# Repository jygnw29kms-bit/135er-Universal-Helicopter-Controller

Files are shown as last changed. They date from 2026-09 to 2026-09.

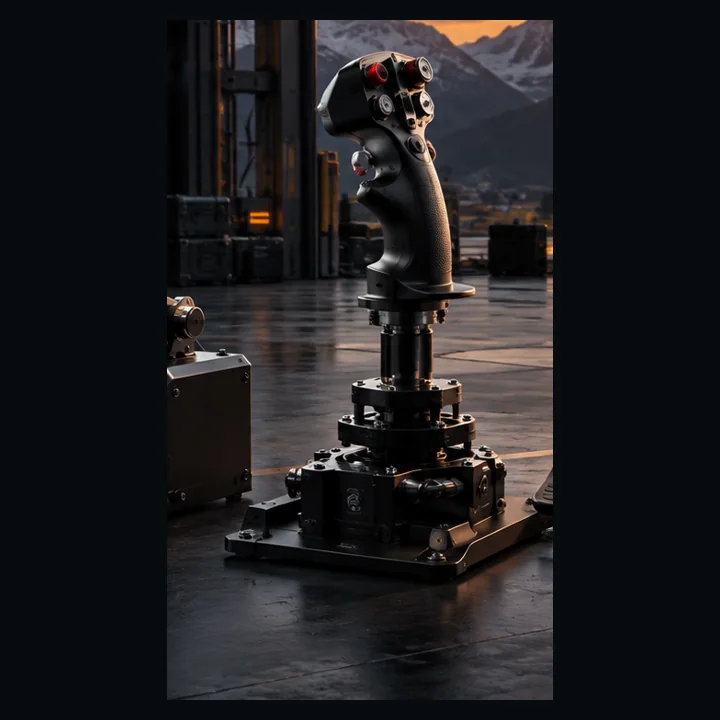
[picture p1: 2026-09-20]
site/assets/cyclic-render.webp

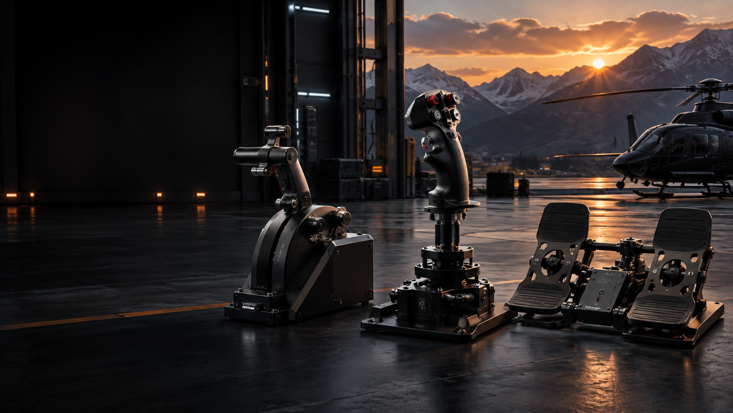
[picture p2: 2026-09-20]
site/assets/hero-render.png

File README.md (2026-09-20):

# 135er Universal Helicopter Controller

Open-source, cross-platform helicopter flight controls for Microsoft Flight Simulator, X-Plane and other simulators.

## Current branch: V1.1 engineering / RC2 candidate

The original V1 RC1 proved the basic architecture and automated build flow. V1.1 hardens the design before physical validation.

Current scope:

- Cyclic: pitch + roll
- Collective: collective + twist throttle
- Pedals: anti-torque yaw + independent left/right toe brakes
- Seven contactless Hall-based analog axes
- Raspberry Pi Pico 2 / RP2350 main controller
- MCP3208 external SPI ADC
- Standard USB HID joystick
- USB CDC diagnostic/configuration console
- 32 HID button bits + 8-way hat
- eight direct debounced button inputs in the first wiring revision
- persistent calibration in flash
- FDM-first PETG mechanical design
- automated STL, host-test and firmware builds

> No V1.x build is physically validated yet. CI success proves that the firmware compiles and CAD renders; it does not prove fit, strength, ergonomics or flight quality.

## Architecture

```text
7 x AS5600 magnetic angle sensors (analog OUT)
                 |
                 v
        MCP3208 8-channel SPI ADC
                 |
                 v
        Raspberry Pi Pico 2 / RP2350
           |                 |
           v                 v
       USB HID          USB CDC console
           |
   Windows / Linux / macOS
           |
      MSFS / X-Plane
```

Using analog output avoids the fixed-I2C-address problem that appears when several AS5600 modules share one bus.

## Axes

1. Cyclic Roll
2. Cyclic Pitch
3. Collective
4. Twist Throttle
5. Anti-Torque Pedals
6. Left Toe Brake
7. Right Toe Brake

## Firmware V1.1 improvements

- real persistent calibration with CRC validation
- first-sample filter seeding; no artificial startup sweep
- configurable filter, inversion, center deadzone and bipolar expo
- direct button and hat input support
- unique USB serial number per Pico 2
- CDC console for calibration and diagnostics
- 1 ms scheduler with overrun counter
- MCP3208 acquisition budget corrected from the original RC1 implementation
- host regression tests for axis math

See `docs/FIRMWARE_V1_1.md`.

## Mechanical V1.1 improvements

- real toe-brake printable modules
- dedicated collective friction adjuster
- modular split cyclic grip with switch openings
- dedicated electronics tray and ventilated lid
- steel primary shafts and bearings remain mandatory
- replaceable Hall sensor carriers and magnet interfaces

## Repository

```text
cad/
  cyclic/
  collective/
  pedals/
  electronics/
  validation/
firmware/
hardware/
docs/
profiles/
site/
.github/workflows/
```

## FDM rules

- target printer envelope: 256 x 256 x 256 mm
- PETG baseline; ASA optional after fit validation
- support-free geometry wherever practical
- steel shafts for primary pivots
- bearings for precision rotation
- M3/M4/M5/M6 standard hardware
- fit-critical dimensions are frozen only after coupon testing

## Print-first workflow

1. Print the validation plate / fit coupons.
2. Record best bearing, shaft, tube, magnet and fastener fits.
3. Freeze dimensional compensation for the actual printer/filament.
4. Print and assemble Cyclic first.
5. Validate Hall alignment and controls.
6. Continue with Collective.
7. Continue with Pedals and toe brakes.
8. Install electronics enclosure and harness.
9. Calibrate through the CDC console.
10. Test MSFS and X-Plane.
11. Only after the validation checklist passes may a release be labeled **VALIDATED**.

## Research basis

The project has been compared against FreeJoy, OpenFFBoard, several open helicopter-collective projects and 3D-printable Hall joystick projects. Adopted ideas and license boundaries are documented in `docs/RESEARCH_NOTES.md`.

No GPL source code from FreeJoy is copied into this MIT firmware.

## Documentation

- `docs/ASSEMBLY_V1.md`
- `docs/FIRMWARE_V1_1.md`
- `docs/PRINTING.md`
- `docs/CALIBRATION.md`
- `docs/VALIDATION_CHECKLIST.md`
- `docs/RC1_STATUS.md`
- `docs/RESEARCH_NOTES.md`
- `hardware/BOM_V1_RC1.md`

## License

Software: MIT.

Hardware/CAD source remains open and the final dedicated hardware-license file will be frozen before the first physically validated release.

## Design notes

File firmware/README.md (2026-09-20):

# Firmware V1.1

Target: Raspberry Pi Pico 2 / RP2350 using Pico SDK and TinyUSB.

## Inputs

Analog chain:

```text
7 x AS5600-class Hall angle sensors (analog OUT)
-> MCP3208
-> RP2350
```

Axis order:
1. Cyclic Roll
2. Cyclic Pitch
3. Collective
4. Twist Throttle
5. Pedals
6. Left Toe Brake
7. Right Toe Brake

Digital V1.1:
- GPIO2..9: buttons 1..8, active low
- GPIO10..13: four-way hat, active low
- five-sample debounce

The HID report still reserves 32 button bits for future expansion.

## USB

Composite USB device:
- HID joystick
- CDC serial configuration/diagnostics

The HID interface exposes seven 16-bit logical axes, 32 buttons and one 8-way hat.

## Calibration

Calibration is stored in the last flash sector with a version field and CRC.

Use the CDC console:

```text
help
status
cal show
cal set roll 800 8100 15400
deadzone roll 120
filter roll 2
expo roll 10
invert roll 0
save
```

See `docs/FIRMWARE_V1_1.md` and `docs/CALIBRATION.md`.

## Timing

MCP3208 SPI runs at 1 MHz. Four readings are accumulated per axis per frame. The main report schedule targets 1 ms and counts overruns for validation.

The four-sample accumulation uses a 0..16380 numeric calibration domain; it must not be described as guaranteed 14-bit ADC ENOB.

## Build

```bash
export PICO_SDK_PATH=/path/to/pico-sdk
cmake -S firmware -B build -DPICO_BOARD=pico2
cmake --build build -j
```

CI also compiles and runs host-side regression tests for axis processing.

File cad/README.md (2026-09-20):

# CAD

All mechanical modules are designed FDM-first.

## Directories

- cyclic/
- collective/
- pedals/
- grips/

## Design requirements

- Every printable part must fit a 256 x 256 mm bed
- Prefer support-free geometry
- Avoid long unsupported bridges
- Prefer screw-fastened assemblies over glued shells
- Use replaceable sensor carriers
- Use metal shafts and bearings for critical pivots
- PETG is the baseline material

Native CAD source files and export STL/3MF files will be added after validation.

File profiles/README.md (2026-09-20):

# Profiles

Profiles will map one physical controller to different helicopter control philosophies.

Initial profile families:

- Universal Helicopter
- Robinson
- Bell
- Airbus / FADEC
- Military
- Custom

Profiles may define:

- Axis curves
- Dead zones
- Collective response
- Twist-throttle behavior
- Governor behavior
- Trim mode
- Button assignments
- Simulator-specific notes

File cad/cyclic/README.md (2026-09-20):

# Cyclic CAD

## First prototype scope

The first CAD iteration will contain:

- Base frame
- Roll gimbal
- Pitch gimbal
- Stick clamp
- Two Hall sensor mounts
- Optional spring mounts
- Top service cover
- Grip interface

## Export policy

For each validated revision, include:

- Native CAD source
- STEP
- STL
- Optional 3MF print project

## Print orientation

Every part should have an obvious flat orientation. Parts that require support should be redesigned unless there is a strong structural reason not to.

## Prototype naming

Use revision naming like:

```text
cyclic_base_v0.1
cyclic_roll_gimbal_v0.1
cyclic_pitch_gimbal_v0.1
cyclic_sensor_mount_v0.1
```

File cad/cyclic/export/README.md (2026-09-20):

# Cyclic exports

This folder will contain validated STL/STEP/3MF exports.

Current source geometry lives in `../src/`.

Do not treat an export as production-ready until it has:
1. printed successfully,
2. passed fit checks for bearings/shafts,
3. passed Hall sensor alignment checks,
4. received a tagged revision.

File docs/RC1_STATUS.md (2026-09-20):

# V1.1 / RC2 engineering status

The project has moved beyond the original RC1 implementation. RC1 remains a useful historical milestone, but the main branch now contains the V1.1 engineering hardening work intended to become RC2.

## Implemented

- RP2350 / Pico 2 target
- seven Hall-based analog axes
- MCP3208 SPI acquisition
- standard USB HID joystick
- composite USB CDC diagnostics/configuration
- 32 HID button bits plus 8-way hat
- eight direct debounced button inputs
- persistent CRC-protected calibration in flash
- configurable inversion, filtering, deadzone and bipolar expo
- unique USB serial number
- acquisition overrun diagnostics
- host-side axis regression tests
- cyclic, collective and pedal CAD
- actual toe-brake CAD modules
- collective friction adjuster
- split cyclic grip prototype
- Pico/MCP3208 electronics enclosure
- automated CAD and firmware builds

## Not physically validated

No V1.x release is allowed to be called VALIDATED until a real printed controller has passed:
- fit coupons
- bearing/shaft/tube fit
- mechanical travel and hard-stop tests
- Hall alignment
- measured calibration
- USB enumeration
- button/hat tests
- sustained overrun check
- MSFS/X-Plane mapping
- extended flight test

## Remaining before RC2 freeze

- print validation plate
- freeze P2S/PETG dimensional compensation
- confirm toe-brake pivot geometry on a physical pedal
- confirm cyclic grip ergonomics and switch selection
- confirm collective friction material and preload
- create final wiring harness drawing
- evaluate dedicated PCB after breadboard/prototype validation

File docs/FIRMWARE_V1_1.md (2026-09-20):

# Firmware V1.1 engineering notes

## Signal path

```
7x AS5600 analog OUT
      |
      v
MCP3208 (SPI, 1 MHz)
      |
      v
4 samples/channel per frame
      |
      v
per-axis IIR filter
      |
      v
calibration + deadzone + optional expo
      |
      v
16-bit logical HID axis
```

The MCP3208 remains a 12-bit ADC. Four samples are accumulated into the existing 0..16380 calibration domain. Do not describe this as a guaranteed 14-bit ENOB measurement.

## 1 ms scheduling

The earlier 16-sample/channel implementation could not meet a true 1 ms seven-axis cycle at the configured SPI speed. V1.1 uses four samples per channel at 1 MHz and tracks missed scheduling windows with `loop_overruns`.

## USB

The controller enumerates as a composite device:
- standard joystick HID
- CDC serial configuration console

HID exposes:
- 7 axes
- 32 button bits
- one 8-way hat

V1.1 directly wires eight debounced buttons. The remaining HID button bits are reserved for future matrix/shift-register expansion.

## Default direct GPIO map

- GPIO2..GPIO9: Buttons 1..8, active low
- GPIO10: Hat Up
- GPIO11: Hat Right
- GPIO12: Hat Down
- GPIO13: Hat Left
- GPIO16: MCP3208 MISO
- GPIO17: MCP3208 CS
- GPIO18: MCP3208 SCK
- GPIO19: MCP3208 MOSI

Inputs use the Pico internal pull-ups.

## Calibration console

Connect to the CDC serial port. Commands:

```text
help
status
cal show
cal set <axis> <min> <center> <max>
invert <axis> <0|1>
deadzone <axis> <0..32766>
filter <axis> <0..5>
expo <axis> <0..100>
save
defaults
```

Axis names:
`roll pitch collective throttle pedals brake_left brake_right`

Changes are made in RAM first. Use `save` to write a CRC-protected configuration to the final flash sector.

## Physical validation rule

Before saving final calibration:
1. verify magnet alignment,
2. move each mechanism through full mechanical travel,
3. inspect `status` raw values,
4. leave electrical headroom before mechanical hard stops,
5. enter measured min/center/max,
6. test simulator direction and center,
7. only then save.

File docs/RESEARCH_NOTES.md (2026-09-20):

# Design research and adopted patterns

This document records concepts reviewed from other open-source simulator-control projects and what was deliberately adopted or rejected.

## Reviewed projects

### FreeJoy
Useful concepts:
- per-axis calibration
- configurable filtering
- inversion/deadzone/curve processing
- buttons, hats and encoders as independent input sources
- MCP3208 support as an external ADC

License note: FreeJoy is GPL-3.0. No FreeJoy source code is copied into this MIT-licensed firmware. Only general architectural ideas are used.

### OpenFFBoard
Useful concepts:
- modular input-source architecture
- separation of input acquisition from USB report generation
- runtime configuration/diagnostics
- CAN as a sensible future expansion path

Not adopted for V1:
- force-feedback motor stack
- HID PID/FFB implementation

### JRNitre/JoystickFreeJoy
Useful concepts:
- 3D-printable modular gimbal construction
- precision bearings and steel hardware instead of printed primary shafts
- contactless high-resolution magnetic sensing
- replaceable sensor/magnet geometry

### KalebClark/HeliCollective
Useful concepts:
- dedicated collective friction hardware
- separate handle/hat components
- serviceable modular parts rather than one monolithic print

### JoePrimo/Helicopter-Collective
Useful concepts:
- button matrix / encoder handling
- practical simulator-oriented grip controls

### geoff-coppertop/helicopter-collective
Useful concepts:
- RP2350 as target MCU
- separation of hardware-independent processing logic from peripheral code
- host-side tests for filtering and processing logic
- diagnostics/status interface

## Adopted for 135er V1.1

- central hardware configuration file
- first-sample filter seeding to remove startup transients
- configurable per-axis filter strength
- center deadzone with range re-scaling
- optional bipolar expo
- persistent calibration in Pico 2 flash
- CDC serial configuration/diagnostic console
- direct debounced buttons plus 8-way hat
- unique USB serial number derived from the Pico board ID
- acquisition timing corrected for the real MCP3208 transaction budget
- loop-overrun counter
- host regression tests for axis processing
- toe-brake mechanical modules
- collective friction adjuster
- split cyclic grip with switch openings
- dedicated electronics tray and lid

## Deliberately deferred

- FFB / active cyclic
- force trim motors/clutches
- CAN/RS485 remote modules
- 32-button shift-register expansion
- graphical desktop configurator
- dedicated controller PCB
- automatic calibration wizard

These belong to later revisions after the passive V1 hardware has been physically validated.

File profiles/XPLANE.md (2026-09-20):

# X-Plane profile

Suggested logical mapping:
- Cyclic Roll -> Roll
- Cyclic Pitch -> Pitch
- Collective -> Collective
- Throttle -> throttle assignment required by the helicopter model
- Pedals -> Yaw
- Toe brakes -> left/right toe brake

Start with linear output and save aircraft-specific response curves in simulator profiles.

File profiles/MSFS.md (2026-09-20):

# Microsoft Flight Simulator profile

Suggested logical mapping:
- Cyclic Roll -> helicopter cyclic lateral / roll axis
- Cyclic Pitch -> helicopter cyclic longitudinal / pitch axis
- Collective -> helicopter collective axis
- Throttle -> helicopter throttle / engine control as required by aircraft
- Pedals -> rudder / anti-torque axis
- Toe brakes -> left/right brake axes

Keep firmware curves linear initially. Apply aircraft-specific sensitivity only after physical calibration.

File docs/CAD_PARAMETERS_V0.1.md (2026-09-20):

# CAD Parameters V0.1

These values are the mechanical baseline for the first Cyclic V1 prototype.

## Global FDM constraints

- Build volume target: 256 x 256 x 256 mm minimum
- Primary material: PETG
- Nominal nozzle: 0.4 mm
- Nominal layer height: 0.20 mm
- Standard wall: 3.2 mm
- Reinforced wall: 5.0-6.0 mm
- Moving-part clearance: 0.30 mm nominal
- Loose service clearance: 0.40 mm nominal
- Bearing pocket allowance: start at +0.10 mm diameter and tune by printer
- Avoid support where possible
- Maximum intended unsupported overhang: 45 deg

## Cyclic base

- Base envelope target: 220 x 180 x 75 mm
- Mounting hole pattern: TBD after first gimbal frame
- Service cover removable from top
- Sensor carriers removable independently from structural gimbal

## Cyclic stick

- Pivot-to-grip reference length: 480 mm
- Tube OD target: 20-22 mm
- Preferred tube: aluminium
- Clamp style: split clamp with M4 fasteners

## Gimbal

- Pitch travel: +/-15 deg
- Roll travel: +/-15 deg
- Main pivot shaft: 8 mm steel
- Bearings: 608-2RS, 8 x 22 x 7 mm
- Gimbal arms should print flat whenever practical
- Bearing housings should be split or clamp-style rather than blind press fits

## Hall sensor geometry

Initial target sensor family:
- AS5600-class absolute magnetic angle sensor for prototype
- Diametric magnet mounted concentric with shaft
- Adjustable sensor gap target: 1-3 mm
- Sensor mount to include slotted adjustment in at least one axis

## Centering

- V1 supports no-spring/free mode
- Optional light centering springs
- Spring anchors must be adjustable
- No mandatory hard center detent

## Fasteners

Preferred standardization:
- M3 for electronics and sensor carriers
- M4 for printed structural joints
- M8 only where used as an actual pivot/shaft substitute

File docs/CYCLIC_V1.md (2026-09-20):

# Cyclic V1

## Baseline geometry

- Floor-mounted dual-gimbal cyclic
- Stick length from pivot: approx. 480 mm
- Pitch travel: approx. +/-15 deg
- Roll travel: approx. +/-15 deg
- Stick tube: 20-22 mm aluminium tube
- Main shafts: 8 mm steel
- Bearings: 608-2RS
- Base target: approx. 220 x 180 x 75 mm

## Sensor concept

Each axis uses a contactless magnetic angle sensor.

- Magnet mounted concentrically on the axis
- Replaceable printed sensor carrier
- No gears or linkages between shaft and sensor
- Target sensor gap: 1-3 mm depending on final sensor choice

## FDM rules

- PETG baseline
- Standard wall thickness: 3.2 mm
- Structural zones: 5-6 mm
- Moving PETG interfaces: 0.25-0.35 mm clearance
- Design for support-free orientation wherever possible
- Split large components into mechanically keyed screw-fastened parts

## V1 printed parts

- Base bottom
- Base left
- Base right
- Pitch gimbal
- Roll gimbal
- Stick clamp A
- Stick clamp B
- X sensor mount
- Y sensor mount
- Spring mounts
- Cover
- Grip halves

## Controls in the grip

- 4-way trim hat
- PTT
- Force-trim release
- Two spare buttons

## Centering

Three intended modes:

- Free: no centering springs
- Light: very soft centering
- Normal: stronger centering for joystick-like preference

Final spring geometry will be adjustable via slotted mounts.

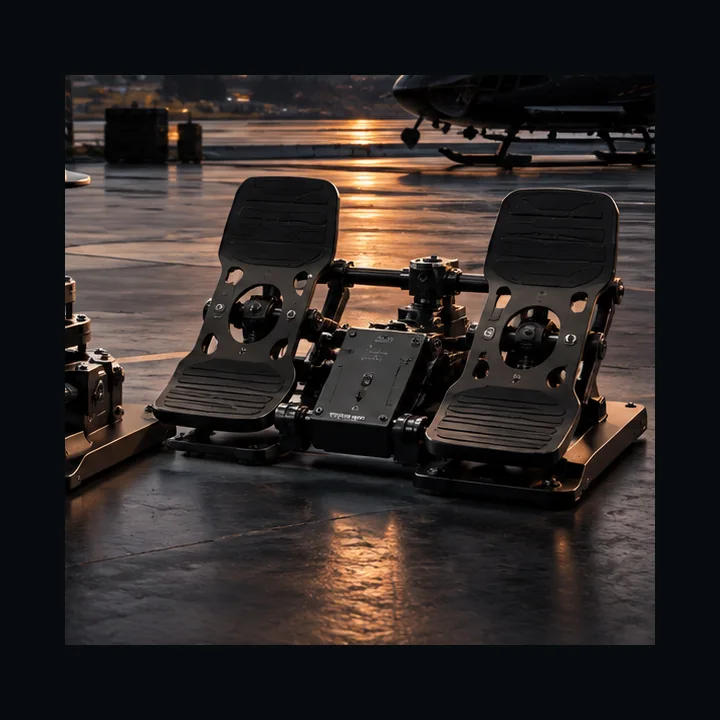
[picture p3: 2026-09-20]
site/assets/pedals-render.webp

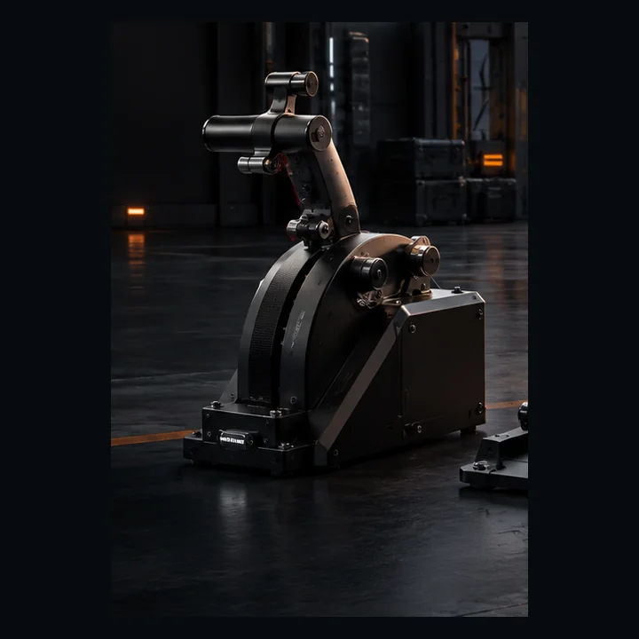
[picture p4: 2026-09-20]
site/assets/collective-render.webp

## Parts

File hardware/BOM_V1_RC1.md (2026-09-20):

# BOM V1.1 / RC2 candidate

## Electronics
- 1x Raspberry Pi Pico 2 (RP2350)
- 1x MCP3208 8-channel 12-bit SPI ADC
- 7x AS5600 magnetic angle sensor modules with analog OUT available
- 7x compatible diametrically magnetized magnets, nominal 6 mm diameter
- 1x USB data cable
- 8x momentary switches minimum for the first direct-button build
- 1x four-way hat mechanism or four momentary switches
- JST-XH or equivalent locking connectors for serviceable module wiring
- 3.3 V sensor rail and common ground distribution

### Recommended signal-integrity parts
For custom/bare sensor carriers rather than finished modules:
- local ceramic decoupling close to each sensor
- MCP3208 supply/reference decoupling close to the ADC
- small bulk capacitor on the sensor rail
- keep analog sensor runs away from USB and fast digital wiring where practical
- join analog/digital grounds cleanly and avoid high-current return paths through sensor ground

Verify what capacitors are already populated on purchased AS5600 breakout boards before duplicating them.

## Cyclic
- 4x 608-2RS bearings minimum
- 2x 8 mm steel shafts
- 1x 20-22 mm OD aluminium tube, about 500 mm
- M3 hardware for sensor/switch modules
- M4 structural screws, washers and lock nuts
- optional light extension springs
- switches for PTT / force-trim / spare functions

## Collective
- bearings to suit final 10 mm pivot arrangement
- 1x 10 mm steel shaft
- 1x 20-22 mm OD aluminium tube
- M4/M5 fasteners
- friction washers/material plus M5 friction-adjuster hardware
- optional rotary encoder / additional switches for aircraft-specific controls

## Pedals
- bearings to suit final 10 mm center pivot
- 1x 10 mm steel center shaft
- 2x 6 mm toe-brake pivot shafts
- M5/M6 structural fasteners
- return springs for left/right toe brake
- three Hall sensor mounts total: yaw + two toe-brake axes

## Printing
- PETG baseline for V1
- ASA optional after dimensional validation
- 0.4 mm nozzle
- 0.20 mm layer height
- 4 perimeters on structural parts
- 30-40% infill baseline
- local reinforcement around pivots/lever/rocker as required

No printed part is intended to replace the primary steel pivot shafts.

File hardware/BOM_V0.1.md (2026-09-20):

# Preliminary BOM V0.1

This is the architecture-stage BOM and will be refined after the first CAD iteration.

## Controller

- 1x RP2350 development board / controller board
- 1x USB-C connection
- Wiring/connectors
- Optional CAN or RS485 transceivers for modular expansion

## Cyclic

- 2x contactless magnetic angle sensors
- 2x compatible diametric magnets
- 4x 608-2RS bearings minimum, final quantity TBD
- 8 mm steel shaft material
- 20-22 mm aluminium tube for cyclic stick
- M3 fasteners for sensors/electronics
- M4 fasteners for structural printed parts
- Optional light extension springs

## Collective

- 2x Hall / magnetic angle sensors
- Bearings and steel pivot shaft
- Aluminium tube
- Buttons/switches for governor, starter and auxiliary functions

## Pedals

- 1x yaw Hall / magnetic sensor
- Optional 2x toe-brake Hall sensors
- Steel main shaft
- Bearings
- M4 structural hardware

## Printing

Baseline material: PETG.
Higher-load alternatives may include ASA or reinforced engineering filament where appropriate.

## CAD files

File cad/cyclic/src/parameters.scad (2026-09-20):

// 135er Universal Helicopter Controller - Cyclic V1 parameters
$fn = 64;

base_x = 220;
base_y = 180;
base_h = 18;
wall = 5;

shaft_d = 8.2;
bearing_od = 22.2;
bearing_w = 7.2;

gimbal_outer_x = 120;
gimbal_outer_y = 100;
gimbal_bar = 18;
gimbal_h = 18;

tube_od = 22.2;
tube_clamp_wall = 6;

sensor_board_x = 23;
sensor_board_y = 23;
sensor_gap = 2.0;

m4_clearance = 4.4;
m3_clearance = 3.4;

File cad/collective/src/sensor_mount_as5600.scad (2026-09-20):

include <../../common.scad>
px=42;py=42;ph=4;m3=3.4;m4=4.5;
difference(){plate(px,py,ph,3);cylinder(h=20,d=12,center=true);for(x=[-9,9])for(y=[-9,9])translate([x,y,-1])cylinder(h=ph+2,d=m3);for(x=[-15,15])translate([x,0,0])slot3d(12,m4,ph+2);}

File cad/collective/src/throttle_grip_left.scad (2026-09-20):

$fn=64;len=145;od=42;id=22.7;
difference(){intersection(){rotate([0,90,0])cylinder(h=len,d=od,center=true);translate([0,12,0])cube([len+4,od,od+4],center=true);}rotate([0,90,0])cylinder(h=len+4,d=id,center=true);}

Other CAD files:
cad/collective/src/throttle_grip_right.scad
cad/collective/src/base.scad
cad/collective/src/friction_adjuster.scad
cad/collective/src/lever_root.scad
cad/common.scad
cad/cyclic/src/base.scad
cad/cyclic/src/gimbal_pitch.scad
cad/cyclic/src/gimbal_roll.scad
cad/cyclic/src/grip_front.scad
cad/cyclic/src/grip_rear.scad
cad/cyclic/src/magnet_hub.scad
cad/cyclic/src/preview_assembly.scad
cad/cyclic/src/sensor_mount_as5600.scad
cad/cyclic/src/stick_clamp.scad
cad/electronics/src/controller_lid.scad
cad/electronics/src/controller_tray.scad
cad/pedals/src/base.scad
cad/pedals/src/pedal_left.scad
cad/pedals/src/pedal_right.scad
cad/pedals/src/rocker.scad
cad/pedals/src/sensor_mount_as5600.scad
cad/pedals/src/toe_brake_left.scad
cad/pedals/src/toe_brake_right.scad
cad/validation/src/fit_coupons.scad
cad/validation/src/validation_plate_01.scad

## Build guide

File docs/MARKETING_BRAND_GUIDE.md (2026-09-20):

# 135er Heli Control — Brand & Marketing Guide

## Positioning

135er Heli Control is an open helicopter-control platform for serious simulator pilots.

It is not positioned as:
- a generic joystick
- a loose STL collection
- a GitHub experiment

It is positioned as:
- a complete helicopter-control system
- built around real helicopter control logic
- modular and serviceable
- contactless on all primary analog axes
- open by design

## Primary brand name

**135er Heli Control**

Product descriptor:
**Universal Helicopter Controller**

## Core promise

A complete helicopter-control system for simulator pilots: Cyclic, Collective, Anti-Torque Pedals and independent Toe Brakes — precise, contactless and open.

## Brand line

**Built for rotary flight.**

German supporting line:
**Vollständige Helicopter-Steuerung. Offen entwickelt. Für echten Rotary-Flight im Simulator.**

## Messaging hierarchy

1. Helicopter-specific control
2. Complete system
3. Precision/contactless sensing
4. Modular/serviceable construction
5. Compatibility
6. Open source / DIY build

Open source is an advantage, not the lead message.

## Tone

Use:
- precise
- calm
- technical
- aviation-oriented
- premium
- confident without overclaiming

Avoid:
- hobbyist slang
- exaggerated superlatives
- unvalidated performance claims
- developer jargon in primary marketing copy
- release/build numbers in hero messaging

## Visual direction

- near-black / graphite backgrounds
- cool cyan as primary accent
- restrained mint/green as secondary technical accent
- large typography
- generous negative space
- cockpit/instrument precision
- no neon cyberpunk overload
- no gamer RGB aesthetic

## Product modules

### Cyclic
Pitch and Roll.
Message: direct, low-friction control around bearing-supported steel pivots.

### Collective
Collective and Twist Throttle.
Message: helicopter-specific lever geometry with adjustable friction.

### Pedals
Anti-Torque Yaw and Toe Brakes.
Message: independent yaw plus separate left/right braking.

## Technical trust points

- 7 Hall-based analog axes
- RP2350 / Raspberry Pi Pico 2
- MCP3208 external ADC
- standard USB HID
- USB CDC configuration/diagnostics
- persistent calibration
- replaceable sensor and mechanical modules
- FDM-first structural parts combined with real steel shafts/bearings

## CTA hierarchy

Primary:
**System entdecken**

Secondary:
**Open Source ansehen**

Technical:
**Build starten**

Validation:
**Entwicklungsstatus ansehen**

## Status wording

Until physical validation:
**V1.1 Engineering Build · RC2 Candidate**

Never describe the project as production-validated before the physical validation checklist has passed.

## SEO themes

Primary:
- helicopter simulator controls
- helicopter cyclic
- helicopter collective
- helicopter pedals
- flight simulator helicopter controls

Secondary:
- MSFS helicopter controls
- X-Plane helicopter controls
- DIY helicopter controls
- open source flight controls
- Hall sensor joystick

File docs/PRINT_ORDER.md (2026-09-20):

# Production Print Order V1.1

Only start this order after the validation coupons have fixed real printer/filament clearances.

## Stage 0 - fit validation
1. validation plate
2. bearing coupon if needed separately
3. shaft coupon
4. tube coupon
5. magnet coupon
6. fastener coupon

## Stage 1 - Cyclic
1. magnet hub
2. Hall sensor mount
3. stick clamp
4. inner gimbal
5. outer gimbal
6. split grip front/rear
7. cyclic base

Stop and assemble the complete Cyclic before continuing.

## Stage 2 - Collective
1. Hall sensor mount
2. friction adjuster
3. throttle grip halves
4. lever root
5. collective base

Stop and verify collective + throttle independently.

## Stage 3 - Pedals
1. Hall sensor mounts
2. toe brake left/right
3. pedal plates
4. rocker
5. pedal base

Stop and verify yaw and both toe-brake axes independently.

## Stage 4 - Electronics
1. controller tray
2. controller lid

The order intentionally prints fit-critical and low-filament parts before large structural parts.

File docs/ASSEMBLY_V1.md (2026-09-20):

# Assembly V1.1 / RC2 candidate

## Before large prints

Print the validation plate and fit coupons first. Do not freeze bearing, shaft, tube or magnet dimensions from nominal CAD alone.

## Cyclic

1. Print magnet hub, Hall sensor mount, stick clamp, inner/outer gimbals and base.
2. Fit 608-2RS bearings only after selecting the correct printed bearing pocket from the coupon.
3. Use 8 mm steel shafts for pitch and roll pivots.
4. Install diametric magnets concentrically in the magnet hubs.
5. Align each AS5600 directly on the pivot axis.
6. Start with roughly 1-2 mm sensor/magnet air gap and verify actual module behavior before closing the housing.
7. Clamp the 20-22 mm aluminium tube.
8. Verify +/-15 degree travel and hard-stop clearance.
9. Fit the split grip only after the gimbal passes its mechanical test.
10. Install PTT / force-trim / spare switches and the hat mechanism.
11. Add optional light centering springs only after friction-free movement is confirmed.

## Collective

1. Print Hall mount, friction adjuster, lever root, throttle grip halves and base.
2. Install the 10 mm steel pivot.
3. Align collective Hall sensing coaxially with the pivot.
4. Install the lever tube.
5. Assemble the twist throttle and its Hall sensor/magnet pair.
6. Fit friction washers and the printed adjuster.
7. Increase friction gradually; the lever must stay where placed without binding.
8. Add grip buttons/encoder only after the two analog axes are verified.

## Pedals

1. Print yaw sensor mount, rocker, base and both pedal structures.
2. Install the 10 mm steel center shaft.
3. Fit the yaw Hall sensor and magnet coaxially.
4. Print both toe-brake modules.
5. Fit 6 mm toe-brake pivots and independent return springs.
6. Use one Hall sensor/magnet pair per toe brake.
7. Check that left/right brake motion does not mechanically alter the yaw axis.
8. Verify pedal travel and both brake returns before wiring.

## Electronics enclosure

1. Print controller tray and lid.
2. Mount Pico 2 and MCP3208 on standoffs or a carrier board.
3. Keep USB/digital wiring separated from long analog sensor runs where practical.
4. Use locking connectors for modules that may be removed for service.
5. Provide strain relief for USB and external harnesses.

## MCP3208 channel map

| Channel | Function |
|---|---|
| CH0 | Cyclic Roll |
| CH1 | Cyclic Pitch |
| CH2 | Collective |
| CH3 | Twist Throttle |
| CH4 | Pedals/Yaw |
| CH5 | Left Toe Brake |
| CH6 | Right Toe Brake |
| CH7 | Reserved |

SPI:
- MISO/DOUT GPIO16
- CS GPIO17
- SCK GPIO18
- MOSI/DIN GPIO19

Before first power-up verify polarity, common ground and that Hall outputs cannot exceed the ADC reference range.

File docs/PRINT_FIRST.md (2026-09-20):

# PRINT FIRST - V1 RC1

Do **not** start with the large cyclic/pedal bases.

Start with `VALIDATION_PLATE_01.stl`. It contains five disconnected fit coupons on one 245 x 137 mm plate.

Use the same printer, nozzle, PETG brand/profile and dimensional settings you intend to use for the final controller.

## Slicer baseline

- 0.4 mm nozzle
- 0.20 mm layer height
- 3 walls for the validation plate
- 4 walls for production controller parts
- 5 top / 5 bottom layers on production parts
- 20% infill for validation plate
- 30-40% infill for production parts
- Supports: OFF
- Scale: 100.00%
- XY compensation / hole compensation: leave at zero/default for the first test
- Print orientation: as supplied, flat on the largest face
- PETG temperatures: use the filament manufacturer's tested/default PETG profile rather than forcing a universal temperature

## Coupon map

### Tube coupon
Left-to-right hole diameters:
22.0 / 22.2 / 22.4 / 22.6 / 22.8 mm

Choose the smallest hole that lets the actual cyclic/collective aluminium tube enter without forcing it.

### Shaft coupon
Upper row, left-to-right:
8.0 / 8.1 / 8.2 / 8.3 / 8.4 mm

Lower row:
10.0 / 10.1 / 10.2 / 10.3 / 10.4 mm

For rotating shafts choose a clean sliding fit with almost no radial play.

### 608 bearing coupon
Left-to-right bearing pocket:
22.0 / 22.1 / 22.2 / 22.3 / 22.4 mm

Choose a pocket where a 608-2RS can be seated by firm thumb pressure and removed without destroying the coupon. Do not choose a brutally tight press fit for PETG.

### Magnet coupon
Left-to-right pocket:
6.0 / 6.1 / 6.2 / 6.3 / 6.4 mm

Choose a snug pocket for the actual diametric magnet. The production hub can additionally retain the magnet with a tiny amount of adhesive.

### Fastener coupon
M3 row:
3.2 / 3.4 / 3.6 mm

M4 row:
4.2 / 4.4 / 4.6 mm

M5 group:
5.2 / 5.4 / 5.6 mm

Choose clearance holes where the screw passes freely without significant slop.

## What to report after this print

Send these five values:
- 608 pocket = __ mm
- 8 mm shaft hole = __ mm
- 10 mm shaft hole = __ mm
- 22 mm tube hole = __ mm
- 6 mm magnet pocket = __ mm
- optional: preferred M3/M4/M5 clearances

Those measurements are the gate for V1 RC1 dimensional freeze. After they are applied, print the Cyclic first, then Collective, then Pedals.

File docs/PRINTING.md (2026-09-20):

# FDM Printing Guide

Designed around a 256 x 256 mm class printer.

PETG baseline:
- 0.4 mm nozzle
- 0.20 mm layer height
- 4 perimeters
- 5 top and 5 bottom layers
- 30-40% infill
- 50% local infill for gimbal, lever root and pedal rocker if desired
- supports off by default

Print parts on their largest flat face. Fit-critical bearing pockets and shaft bores should be tested first if the printer is not dimensionally calibrated.

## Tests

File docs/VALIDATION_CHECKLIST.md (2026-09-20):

# V1.1 / RC2 Validation Checklist

The repository may be a buildable release candidate, but it is not a physically validated controller until every required item below has passed on real hardware.

## Stage 0 - dimensional coupons
- [ ] 608 bearing pocket selected
- [ ] 8 mm shaft fit selected
- [ ] 10 mm shaft fit selected
- [ ] 22 mm tube fit selected
- [ ] 6 mm magnet pocket fit selected
- [ ] M3/M4/M5 clearances selected
- [ ] chosen compensation values recorded

## Cyclic mechanical
- [ ] inner/outer gimbal print cleanly
- [ ] bearings seat without cracking or excessive play
- [ ] 8 mm steel pivots fit correctly
- [ ] +/-15 degree pitch travel without interference
- [ ] +/-15 degree roll travel without interference
- [ ] mechanical hard stops protect sensors/cables
- [ ] centering springs return consistently if fitted
- [ ] grip halves fit and remain rigid under normal control loads
- [ ] PTT / force-trim / hat controls can be serviced without reprinting the gimbal

## Collective mechanical
- [ ] 10 mm pivot fit confirmed
- [ ] collective remains in position with friction adjusted
- [ ] friction is smooth through full travel
- [ ] twist throttle rotates freely without moving collective
- [ ] grip fasteners remain accessible
- [ ] wiring does not wind up through throttle travel

## Pedals mechanical
- [ ] main 10 mm yaw shaft fit confirmed
- [ ] yaw rocker travels freely
- [ ] left toe-brake pivot fits and returns
- [ ] right toe-brake pivot fits and returns
- [ ] applying either toe brake does not shift yaw position
- [ ] pedal/rocker structure shows no visible flex under normal foot load

## Hall sensor alignment
- [ ] all magnets are diametrically magnetized
- [ ] magnet centers are aligned to sensor axes
- [ ] sensor air gaps are repeatable
- [ ] no axis electrically clips before its mechanical hard stop
- [ ] center noise is recorded for roll/pitch/yaw
- [ ] raw min/center/max values recorded for all seven axes

## Electrical
- [ ] 3.3 V rail verified before connecting sensors
- [ ] sensor supply and MCP3208 reference verified
- [ ] common ground continuity verified
- [ ] all seven outputs remain within ADC input/reference range
- [ ] MCP3208 SPI communication stable
- [ ] USB cable strain relief fitted
- [ ] module connectors are keyed/labeled
- [ ] analog harness is routed away from noisy/high-current wiring where practical

## USB / firmware
- [ ] HID joystick enumerates
- [ ] CDC console enumerates
- [ ] USB serial number is unique/stable across reconnects
- [ ] all seven axes enumerate
- [ ] direct buttons 1-8 operate
- [ ] hat cardinal directions operate
- [ ] hat diagonals operate
- [ ] opposite hat directions cancel safely
- [ ] `cal show` reports live raw values
- [ ] calibration survives power cycle after `save`
- [ ] CRC/default fallback tested once
- [ ] inversion works
- [ ] deadzone works without losing full endpoints
- [ ] filter settings work
- [ ] expo works on bipolar axes
- [ ] `loop_overruns` remains zero or acceptably low during sustained operation
- [ ] no visible startup axis sweep after USB connection

## Simulator
- [ ] MSFS mapping test
- [ ] X-Plane mapping test
- [ ] cyclic directions correct
- [ ] collective direction correct
- [ ] pedal direction correct
- [ ] left/right toe brakes map independently
- [ ] throttle behavior tested on at least one piston helicopter
- [ ] throttle/governor behavior tested on at least one turbine helicopter where applicable
- [ ] buttons and hat map reliably

## Endurance
- [ ] minimum 30 minute powered idle test
- [ ] minimum 30 minute continuous control-movement test
- [ ] USB reconnect test
- [ ] power-cycle calibration persistence test
- [ ] fast full-travel movement does not cause missed/erratic reports
- [ ] no fastener loosening after first flight session

Only after the required checks pass may a release be tagged **VALIDATED**.

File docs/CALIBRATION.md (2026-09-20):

# Calibration

V1.1 supports persistent per-axis calibration through the USB CDC console.

Bipolar axes:
- Cyclic Roll
- Cyclic Pitch
- Pedals

Unipolar axes:
- Collective
- Throttle
- Left Brake
- Right Brake

## Procedure

1. Print and evaluate the fit-validation parts first.
2. Mechanically assemble the axis with hard stops in place.
3. Align the AS5600 and diametric magnet concentrically.
4. Open the controller CDC serial port.
5. Run `status`.
6. Move the axis to both physical endpoints and record raw values.
7. For bipolar axes record the relaxed mechanical center.
8. Keep a small electrical margin before the mechanical hard stops.
9. Apply the values with `cal set`.
10. Verify direction, center and full travel.
11. Use `save` only after the values are confirmed.

Example:

```text
cal set roll 840 8120 15450
deadzone roll 120
filter roll 2
expo roll 10
save
```

## Acceptance targets

- stable center without visible oscillation
- no electrical clipping before mechanical stops
- full logical range close to mechanical endpoints
- no unintended inversion
- cyclic/pedal center error below 1%
- `loop_overruns` remains zero or negligible during normal operation

The AS5600 magnet must be centered carefully. With a nominal 6 mm magnet, small lateral misalignment has a meaningful effect on angular accuracy.

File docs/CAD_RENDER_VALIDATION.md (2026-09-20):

# CAD Render Validation - V1 RC1

Local validation was performed by rendering every production OpenSCAD source to STL and checking the resulting meshes.

## Result

- 16/16 production parts rendered successfully.
- 16/16 meshes reported watertight/manifold.
- Every individual part fits inside a 256 x 256 x 256 mm build volume.

| Part | Bounding box mm |
|---|---:|
| Cyclic base | 220 x 180 x 21 |
| Cyclic outer gimbal | 124 x 104 x 18 |
| Cyclic inner gimbal | 86 x 68 x 34 |
| Cyclic stick clamp | 54 x 38 x 46 |
| Cyclic sensor mount | 50 x 42 x 8 |
| Cyclic magnet hub | 18 x 18 x 10 |
| Collective base | 190 x 90 x 50.15 |
| Collective lever root | 89 x 50 x 28 |
| Collective throttle grip left | 145 x 30 x 42 |
| Collective throttle grip right | 145 x 30 x 42 |
| Collective sensor mount | 42 x 42 x 4 |
| Pedal base | 240 x 180 x 54 |
| Pedal rocker | 210 x 48 x 24 |
| Pedal left | 82 x 150 x 12 |
| Pedal right | 82 x 150 x 12 |
| Pedal sensor mount | 42 x 42 x 4 |

This verifies that the source produces closed printable meshes and meets the target envelope. It does not replace a real print, dimensional fit check or strength test.

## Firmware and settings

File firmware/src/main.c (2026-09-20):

#include "pico/stdlib.h"
#include "bsp/board.h"
#include "tusb.h"
#include "axis.h"
#include "calibration.h"
#include "cli.h"
#include "config.h"
#include "hid_report.h"
#include "inputs.h"
#include "mcp3208.h"
#include <string.h>

static calibration_data_t cal;
static axis_state_t axes[HELI_AXIS_COUNT];
static heli_hid_report_t report;
static heli_diagnostics_t diag;

static void sample_axes(void) {
    uint16_t value[HELI_AXIS_COUNT];
    for (uint8_t i = 0; i < HELI_AXIS_COUNT; ++i) {
        uint16_t raw = mcp3208_read_oversampled(i);
        diag.latest_raw[i] = raw;
        value[i] = axis_process(&axes[i], raw);
    }

    report.cyclic_roll = value[0];
    report.cyclic_pitch = value[1];
    report.collective = value[2];
    report.throttle = value[3];
    report.pedals = value[4];
    report.brake_left = value[5];
    report.brake_right = value[6];
}

int main(void) {
    board_init();
    mcp3208_init();
    inputs_init();

    calibration_load(&cal);
    for (uint8_t i = 0; i < HELI_AXIS_COUNT; ++i)
        axis_state_init(&axes[i], &cal.axis[i]);

    hid_report_init(&report);
    memset(&diag, 0, sizeof(diag));
    cli_init(&cal, axes, &diag);

    tusb_init();

    absolute_time_t next = delayed_by_us(get_absolute_time(), HELI_HID_INTERVAL_US);

    while (true) {
        tud_task();
        cli_task();

        if (time_reached(next)) {
            int64_t lateness = -absolute_time_diff_us(get_absolute_time(), next);
            if (lateness > (int64_t)HELI_HID_INTERVAL_US) {
                ++diag.loop_overruns;
                next = delayed_by_us(get_absolute_time(), HELI_HID_INTERVAL_US);
            } else {
                next = delayed_by_us(next, HELI_HID_INTERVAL_US);
            }

            inputs_task();
            sample_axes();
            report.buttons = inputs_buttons();
            report.hat = inputs_hat();

            if (tud_hid_ready()) {
                tud_hid_report(0, &report, sizeof(report));
                ++diag.report_count;
            }
        }
    }
}

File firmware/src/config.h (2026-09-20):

#pragma once
#include <stdint.h>

#define HELI_AXIS_COUNT 7
#define HELI_BUTTON_COUNT 8
#define HELI_HID_INTERVAL_US 1000u

#define HELI_SPI_BAUD_HZ 1000000u
#define HELI_ADC_SAMPLES_PER_AXIS 4u
#define HELI_ADC_RAW_MAX 16380u

#define HELI_PIN_SPI_MISO 16
#define HELI_PIN_SPI_CS   17
#define HELI_PIN_SPI_SCK  18
#define HELI_PIN_SPI_MOSI 19

// Eight active-low direct buttons. Expansion beyond eight buttons is planned
// via a shift-register/I/O-expander source without changing the HID format.
static const uint8_t HELI_BUTTON_PINS[HELI_BUTTON_COUNT] = {2,3,4,5,6,7,8,9};

// Active-low four-way hat. Diagonals are generated from simultaneous presses.
#define HELI_PIN_HAT_UP    10
#define HELI_PIN_HAT_RIGHT 11
#define HELI_PIN_HAT_DOWN  12
#define HELI_PIN_HAT_LEFT  13

#define HELI_INPUT_DEBOUNCE_SAMPLES 5u

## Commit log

2026-09-20 Add cad/README.md
2026-09-20 Add firmware/src/calibration.h
2026-09-20 Add firmware/src/calibration.c
2026-09-20 Add cad/cyclic/README.md
2026-09-20 Add Cyclic V1 CAD source: parameters.scad
    [parameters.scad]
2026-09-20 Add Cyclic V1 CAD source: base.scad
    [base.scad]
2026-09-20 Add Cyclic V1 CAD source: gimbal_roll.scad
    [gimbal_roll.scad]
2026-09-20 Add Cyclic V1 CAD source: gimbal_pitch.scad
    [gimbal_pitch.scad]
2026-09-20 Add Cyclic V1 CAD source: sensor_mount_as5600.scad
    [sensor_mount_as5600.scad]
2026-09-20 Add Cyclic V1 CAD source: stick_clamp.scad
    [stick_clamp.scad]
2026-09-20 Add Cyclic V1 CAD source: preview_assembly.scad
    [preview_assembly.scad]
2026-09-20 Add Cyclic V1 CAD source: README.md
2026-09-20 Update firmware/src/calibration.h for V1 RC1
2026-09-20 Update firmware/src/calibration.c for V1 RC1
2026-09-20 Add cad/common.scad for V1 RC1
    [common.scad]
2026-09-20 Add cad/cyclic/src/magnet_hub.scad for V1 RC1
    [magnet_hub.scad]
2026-09-20 Add cad/collective/src/base.scad for V1 RC1
    [base.scad]
2026-09-20 Add cad/collective/src/lever_root.scad for V1 RC1
    [lever_root.scad]
2026-09-20 Add cad/collective/src/throttle_grip_left.scad for V1 RC1
    [throttle_grip_left.scad]
2026-09-20 Add cad/collective/src/throttle_grip_right.scad for V1 RC1
    [throttle_grip_right.scad]
2026-09-20 Add cad/collective/src/sensor_mount_as5600.scad for V1 RC1
    [sensor_mount_as5600.scad]
2026-09-20 Add cad/pedals/src/base.scad for V1 RC1
    [base.scad]
2026-09-20 Add cad/pedals/src/rocker.scad for V1 RC1
    [rocker.scad]
2026-09-20 Add cad/pedals/src/pedal_left.scad for V1 RC1
    [pedal_left.scad]
2026-09-20 Add cad/pedals/src/pedal_right.scad for V1 RC1
    [pedal_right.scad]
2026-09-20 Add cad/pedals/src/sensor_mount_as5600.scad for V1 RC1
    [sensor_mount_as5600.scad]
2026-09-20 Add docs/ASSEMBLY_V1.md for V1 RC1
2026-09-20 Add docs/CALIBRATION.md for V1 RC1
2026-09-20 Add docs/PRINTING.md for V1 RC1
2026-09-20 Add .github/workflows/build-cad.yml for V1 RC1
2026-09-20 Fix CAD CI to render production parts only
2026-09-20 Fix Pico SDK path in firmware CI
2026-09-20 Document V1 RC1 STL render and manifold validation
2026-09-20 Record successful CAD and RP2350 CI builds
2026-09-20 Add print-first validation: cad/validation/src/fit_coupons.scad
    [fit_coupons.scad]
2026-09-20 Add print-first validation: cad/validation/src/validation_plate_01.scad
    [validation_plate_01.scad]
2026-09-20 Add print-first validation: docs/PRINT_FIRST.md
2026-09-20 Add print-first validation: docs/PRINT_ORDER.md
2026-09-20 Include print-first validation plate in CAD artifacts
2026-09-20 Switch dezender deployment to password authentication
2026-09-20 Firmware V1.1: update firmware/src/calibration.h
2026-09-20 Firmware V1.1: update firmware/src/calibration.c
2026-09-20 CAD V1.1: add cad/pedals/src/toe_brake_left.scad
    [toe_brake_left.scad]
2026-09-20 CAD V1.1: add cad/pedals/src/toe_brake_right.scad
    [toe_brake_right.scad]
2026-09-20 CAD V1.1: add cad/collective/src/friction_adjuster.scad
    [friction_adjuster.scad]
2026-09-20 CAD V1.1: add cad/cyclic/src/grip_front.scad
    [grip_front.scad]
2026-09-20 CAD V1.1: add cad/cyclic/src/grip_rear.scad
    [grip_rear.scad]
2026-09-20 CAD V1.1: add cad/electronics/src/controller_tray.scad
    [controller_tray.scad]
2026-09-20 CAD V1.1: add cad/electronics/src/controller_lid.scad
    [controller_lid.scad]
2026-09-20 CAD V1.1: fix standalone right toe brake
    [toe_brake_right.scad]
2026-09-20 CAD V1.1: include electronics and new production parts in CI
2026-09-20 V1.1 engineering: update docs/CALIBRATION.md
2026-09-20 V1.1 engineering: refresh docs/ASSEMBLY_V1.md
2026-09-20 V1.1 engineering: refresh docs/PRINT_ORDER.md
2026-09-20 Deploy: switch heli website to exact SSH Plesk webroot
2026-09-20 Website: show Heli Control STL previews with P2S profiles
2026-09-20 Style STL preview and P2S profile section
2026-09-20 Fix Heli Control STL/P2S card wrapping and responsive layout
2026-09-20 Website: add direct Heli Control STL downloads
2026-09-20 Deploy: build and publish STL download packages
2026-09-20 Website: expose individual STL files for direct download
2026-09-20 Deploy: validate non-empty STL files and direct downloads
2026-09-20 site: add live original STL geometry overview
2026-09-20 site: style live STL overview
2026-09-20 build: add automatic STL preview renderer
2026-09-20 deploy: auto-render STL preview images and manifest
2026-09-20 cad: generate preview images for every STL
2026-09-20 site: drive STL preview gallery from generated manifest
2026-09-20 fix: quote STL path in OpenSCAD preview wrapper
2026-09-20 site: style generated STL preview images
2026-09-20 fix: make STL preview deploy workflow valid YAML
2026-09-20 fix: render STL previews from quoted absolute paths
